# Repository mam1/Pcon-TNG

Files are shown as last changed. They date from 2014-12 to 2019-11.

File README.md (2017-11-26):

## PCON-TNG
------
### *** under construction and not stable ***
------
These are my notes on developing a multi channel programmable HVAC controller. The current iteration of the system is comprised of several ESP8266 modules, a BeagleBone Black (BBB), a BBB custom Control Cape and Digital IO Board(s) from Parallax. The system supports 16 channels.

A daemon (Dcon) is started as part of the boot process of the BeagleBone. The daemon decides if a channel should be on or off.  It does this by looking at a memory mapped file (ipc.dat). The memory mapped file creates a persistent space in virtual memory allowing processes to communicate.  It is maintained by a user interface process (Pcon).  Pcon is only active when a user is interacting with the system.  Temperature and humidity data is collected by ESP8266 modules. The ESP8266 modules read HDT22 sensors and use a wireless connection to post the data to the cloud (ThingSpeak) and to an Apache sever running on the BBB. A CGI on the BBB makes the data available to the daemon by updating shared memory and posts the data to a SQL database running on the Linux development machine.

A channel can be controlled by:

* time of day
* time of day and a sensor value
* manually

The BBB Control Cape (part of this project) maps 16 BeagleBone gpio pins to 2 2x10 pin headers.  Each header can drive 1 Parallax Digital IO board (DIOB).  It also connects 4 gpio pins to a heart beat display on the cape.

The Pcon application runs on the BBB.  It interacts with the daemon using shared memory.  Pcon provides a state machine driven user interface to configure channels, build and maintain schedules, query sensor and channel data, manually control channel states, etc.
- - - - - - - - -
#### Hardware
  * **BeagleBone Black Rev C - 4GB Flash, adafruit**
  * **BBB Control Cape**
    *  2 - 2 x 10 headers, DIOB control
            * Digital IO Board (DIOB), Sharp solid state relays part# S202S02F, Parallax
    *  4 - heart beat leds
  * **Wireless Sensors**
    * ESP8266 NodeMCU Dev Board, R2, Electro Dragon
    * DHT22 temperature/humidity sensor, Electro Dragon
    * 0.96” 128*64 OLED Display (i2c), Electro Dragon

##### BeagleBone GPIO assignments
                           {header,pin,gpio}
    * #define _CHAN0          {8,27,86}
    * #define _CHAN1          {8,28,88}
    * #define _CHAN2          {8,29,87}
    * #define _CHAN3          {8,30,89}
    * #define _CHAN4          {8,31,10}
    * #define _CHAN5          {8,32,11}
    * #define _CHAN6          {8,33,9}
    * #define _CHAN7          {8,34,81}
    * #define _CHAN8          {8,35,8}
    * #define _CHAN9          {8,36,80}
    * #define _CHAN10         {8,37,78}
    * #define _CHAN11         {8,38,79}
    * #define _CHAN12         {8,39,76}
    * #define _CHAN13         {8,40,77}
    * #define _CHAN14         {8,41,74}
    * #define _CHAN15         {8,42,75}
    * #define _HB0            {8,43,72}
    * #define _HB1            {8,44,73}
    * #define _HB2            {8,45,70}
    * #define _HB3            {8,46,71}

##### Parallel connection between BBB and DIOB(s)

#### Development Environment:

All code is stored on github.  The repository is cloned on two development machines.  At one site I have a Linux box running Mint 18.x and at the other I have have an iMac running OS X 10.10.x . The Bone is connected to my network. I can access it from either site using ssh. My makefiles use rsync to move the binaries from the development machines to the Bone as part of the build process. 

When cross compiling for the Bone on OS X I am using a tool chain I got from http://will-tm.com/cross-compiling-mac-os-x-mavericks. The only thing I needed to do was to create a case sensitive partition before copying the files from the .dmg file.  On the Linux box I tried installing a cross compile tool chain using the Mint software manager and experienced a lot of problems. After spending a lot of time dealing with missing files I gave up and installed the linaro-arm-linux-gnueabihf-4.9-2014.09_linux tool chain and it worked on the first try.

#### Language
* C - BBB
* Lua - ESP8266
* Bash Script
* Make

#### Envirnoment
* Development machines
	*	Mint 18.x - Intel Core i5-6600K 3.5GHz Quad-Core, Asus Z170-A ATX LGA1151 Motherboard Processor
	*	OS X 10.11.x - 3.4 GHz Intel Core i7 (iMac)
* BeagleBone Black (rev C)- Debian, jessie
* ESP8266 (nodeMCU dev board r2) - nodeMCU firmware 

#### Channels and Schedules 
A channel is controlled by a schedule. There is a different schedule for each day of the week. Each channel has it own set of schedules. Channels 0-7 can switch a 60 volt 1.1 amp loads.  Channels 8 -15 can switch 120 volt 8 amp loads.  Each channel can be set manually to on or off.  Channels and also be controlled by time of day, i.e. on at 8:00 off at 14:30 or sensor value and time.  When a channel is controlled by time and sensor once a minute the remote sensor value is compared to the value stored in the schedule for current time and day of the week. If the actual values exceeds the schedule value the channel is turned off when. If the schedule values is less than the actual value the channel is turned on.  

##### Schedules:
A schedule is a list of times and corresponding states.  A channel that is controlled by time will be a list of times and states.  For example, a schedule of:

* 1:00  on
* 13:00 off

will result in the channel turning on at 1:00AM and off at 1:00PM.  If the current time is between 13:00 and 24:00 or between 0:0 and 13:00 the channel will be off.  Between 1:00 and 13:00 it will be on. While a schedule of:

* 1:00  off
* 13:00 on 

will result in the channel being off between 1:00 - 13:00. It will be on at any time before 1:00 or after 13:00.

* 1:00  on
* 13:00 off
* 18:00 on

will result in the channel turning on at 1:00, off at 13:00 and on at 18:00.  If the current time is between 1:00 and 13:00 the channel will be on, between 13:00 and 18:00 it will be off, between 18:00 and 0:0 it will be on and between 0:0 and 13:00 it will also be on.  

#### Application Architecture
##### Interprocess Communication (BBB)
A memory mapped file is used to create a shared memory space in virtual memory.  This file contains communication, system, schedule and sensor data.  A daemon is started as part of the boot process on the BBB. If the daemon does not find the file it creates and initializes it.  Other processes can access this shared memory space.  Semaphores are used to control access to shared memory.
##### Processes
A deamon (Dcon) running on the BBB communicates with the DIOB(s).  It uses data located in a memory mapped file (ipc.dat) and the real time clock to determine the state of each channel. The state of each channel is reset once every minute. The daemon does not require any other processes to be active.

A command processor (Pcon) is the user interface to the system.  It allows the user to modify the data in shared memory.

ESP8266 modules run independently of other system components.  Each module posts its sensor readings to an Apache web server running on the BBB.  A CGI (Scon) loads the readings into  shared memory. 
##### Command Processor
The command processor is the most complex part of this project. 

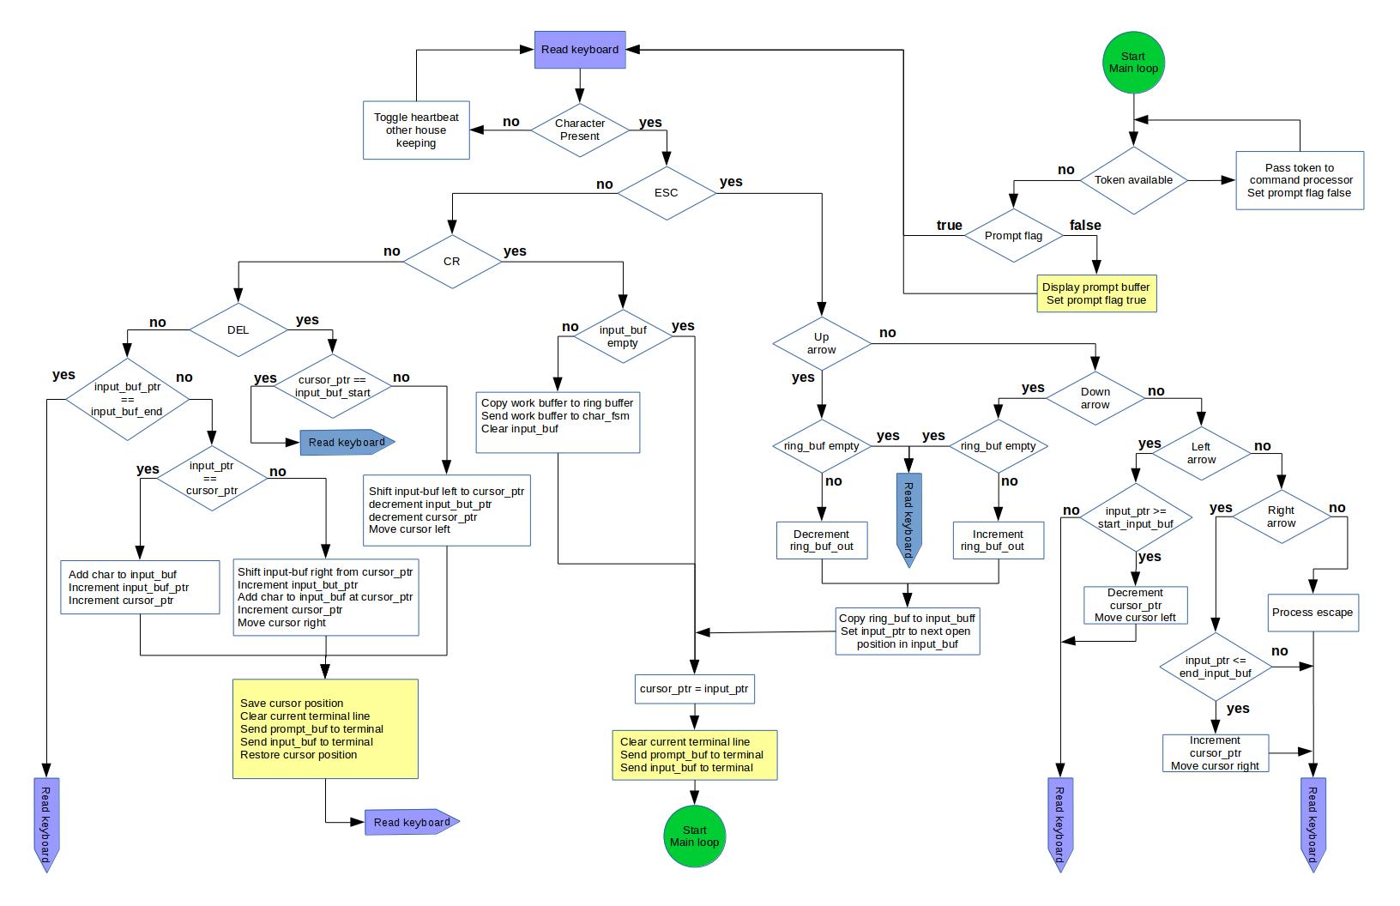
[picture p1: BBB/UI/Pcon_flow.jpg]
Pcon flow chart


The use of unbuffered input allows the application to mediately react to the press of the ECS key, but it requires that the command processor handle the arrow and delete keys. The command processor maintains a buffer which matches the user's screen. The process loops waiting for a character to be detected.  ESC, Del, up_arrow, down_arrow, left_arrow and right_arrow are handled directly.  An ESC will clear all buffers and reset both state machines.  The delete and arrow commands work as they do on the command line. Any other character is passed to the first state machine (char_fsm).  It parses the input stream into tokens and pushes them on to FIFO stack.  A CR will cause char_fsm to pass the stack of tokes to the command processor.  

The command processor pops tokens off the stack and feeds them to a second fsm (cmd_fsm).  It takes some action based on the token.  If more input is required it is popped off the stack, if present, or the user is prompted. This continues until the stack is empty. Then the command processor lets the cms_fsm know there is no more input then continues the main loop, waiting for user input. 

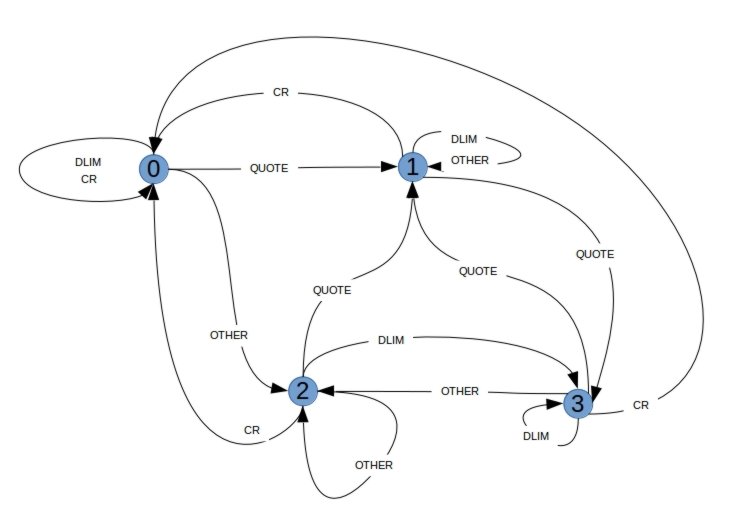
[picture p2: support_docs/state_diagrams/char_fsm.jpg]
character parser state diagram character parser FSM


When the main event loop detects a non-empty token stack it passes the stack to a second state machine (cmd_fsm) which processes the token stack. 

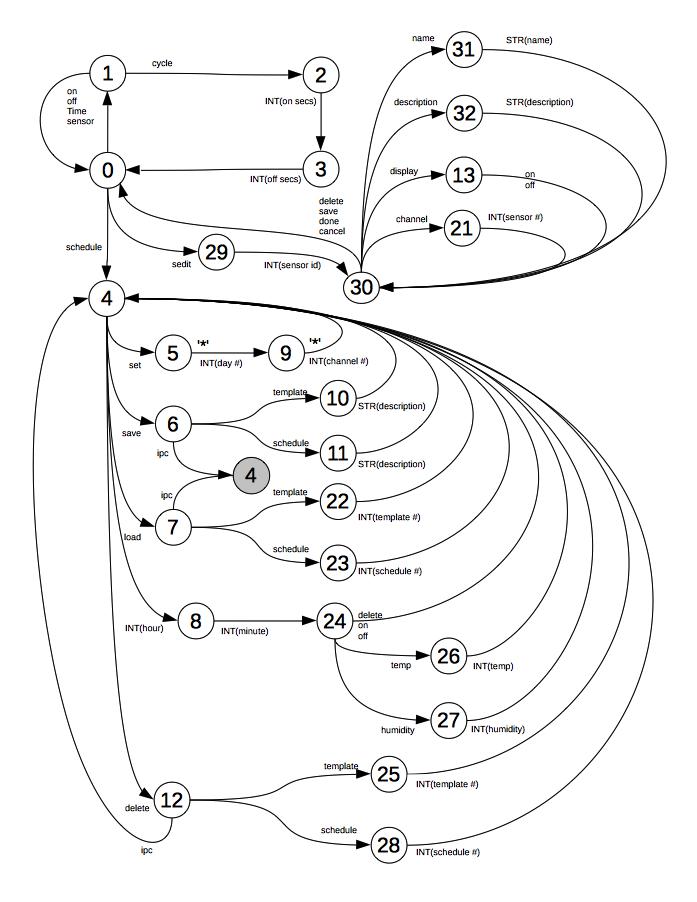
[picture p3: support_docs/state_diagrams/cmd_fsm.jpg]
command parser state diagram command parser FSM


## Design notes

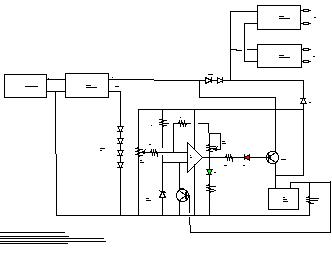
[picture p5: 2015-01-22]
support_docs/hardware_overview/power.jpeg

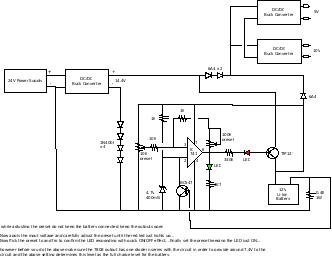
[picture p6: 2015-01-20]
support_docs/hardware_overview/power.jpg

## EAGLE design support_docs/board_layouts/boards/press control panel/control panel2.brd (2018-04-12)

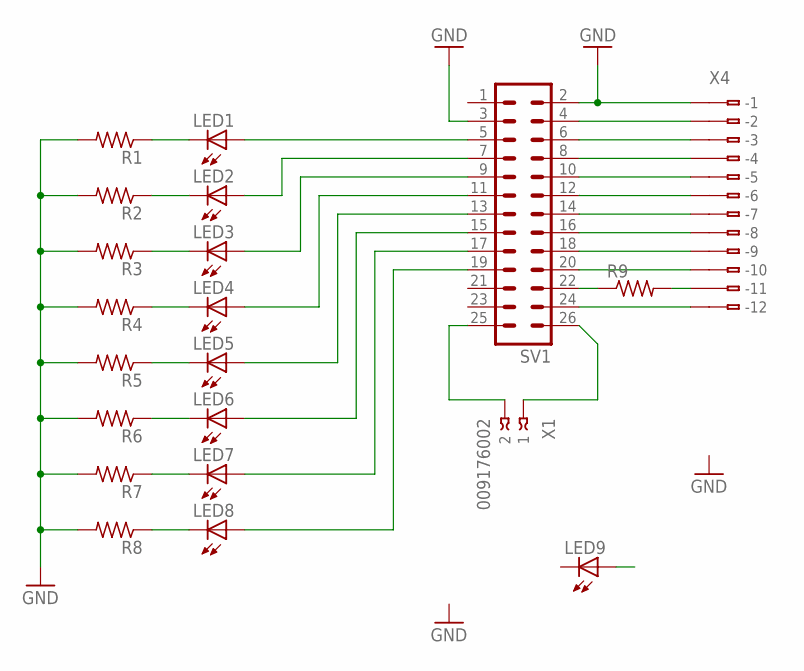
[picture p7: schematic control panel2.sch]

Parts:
LED1, LED2, LED3, LED4, LED5, LED6, LED7, LED8, LED9: LED3MM
R1, R2, R3, R4, R5, R6, R7, R8: R-US_0309/V; 0309V
R9: R-US_0204/7; 0204/7
SV1: MA13-2
X1: 009176002
X4: 233-212

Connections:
GND: R1.2, R2.2, R3.2, R4.2, R5.2, R6.2, R7.2, R8.2, SV1.2, SV1.3, X4.B1 (B-1)
unnamed: LED1.A, SV1.5
unnamed: LED2.A, SV1.7
unnamed: LED3.A, SV1.9
unnamed: LED4.A, SV1.11
unnamed: LED5.A, SV1.13
unnamed: LED6.A, SV1.15
unnamed: LED7.A, SV1.17
unnamed: LED8.A, SV1.19
unnamed: LED1.K (C), R1.1
unnamed: LED2.K (C), R2.1
unnamed: LED3.K (C), R3.1
unnamed: LED4.K (C), R4.1
unnamed: LED5.K (C), R5.1
unnamed: LED6.K (C), R6.1
unnamed: LED7.K (C), R7.1
unnamed: LED8.K (C), R8.1
unnamed: SV1.24, X4.B12 (B-12)
unnamed: SV1.4, X4.B2 (B-2)
unnamed: SV1.6, X4.B3 (B-3)
unnamed: SV1.8, X4.B4 (B-4)
unnamed: SV1.10, X4.B5 (B-5)
unnamed: SV1.12, X4.B6 (B-6)
unnamed: SV1.14, X4.B7 (B-7)
unnamed: SV1.16, X4.B8 (B-8)
unnamed: SV1.25, X1.2
unnamed: SV1.26, X1.1
unnamed: SV1.18, X4.B9 (B-9)
unnamed: SV1.20, X4.B10 (B-10)
unnamed: R9.1, SV1.22
unnamed: R9.2, X4.B11 (B-11)

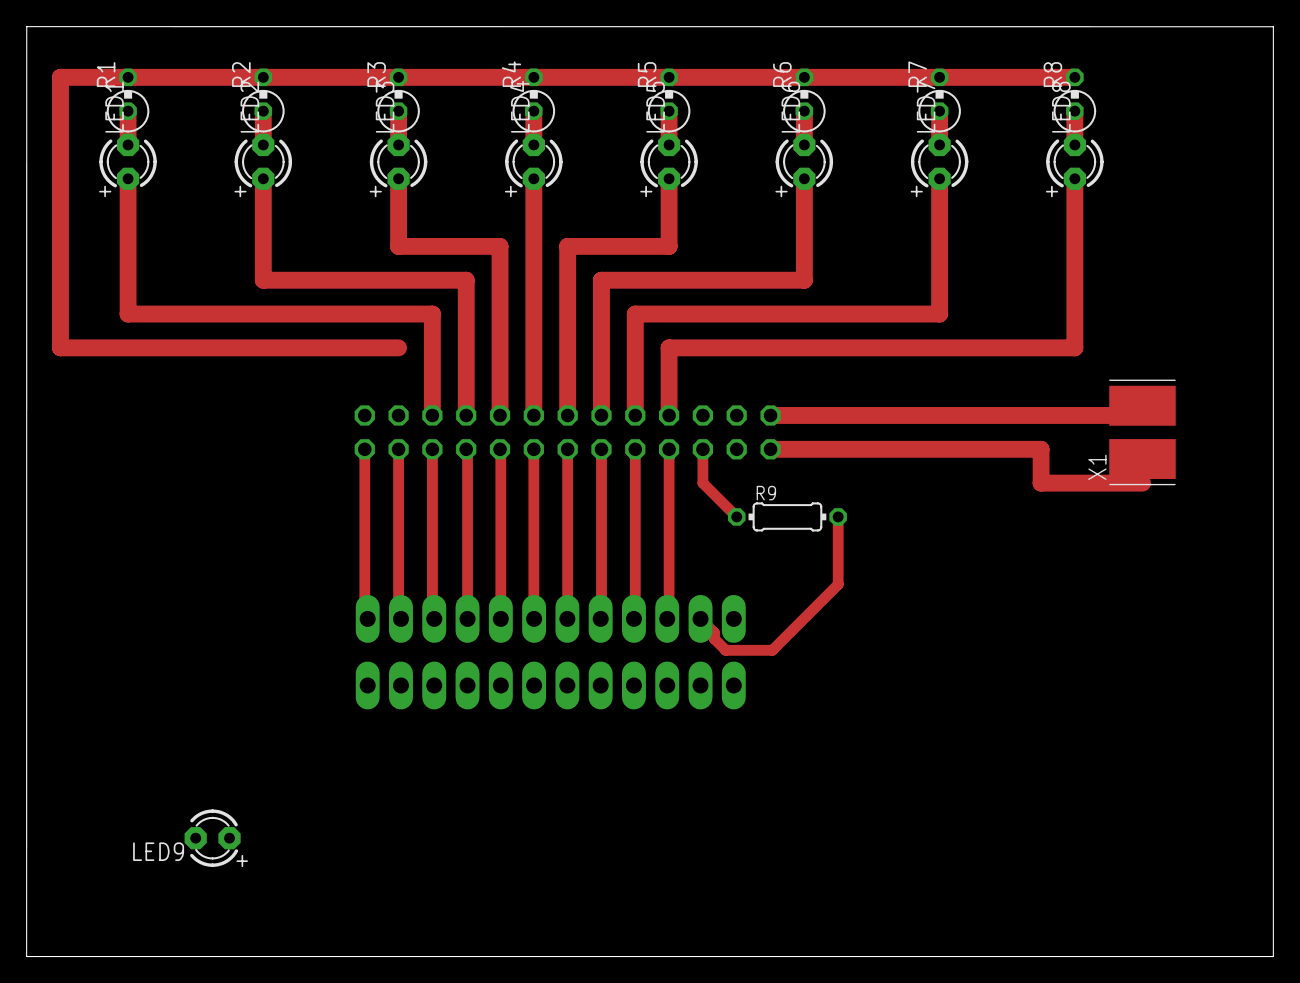
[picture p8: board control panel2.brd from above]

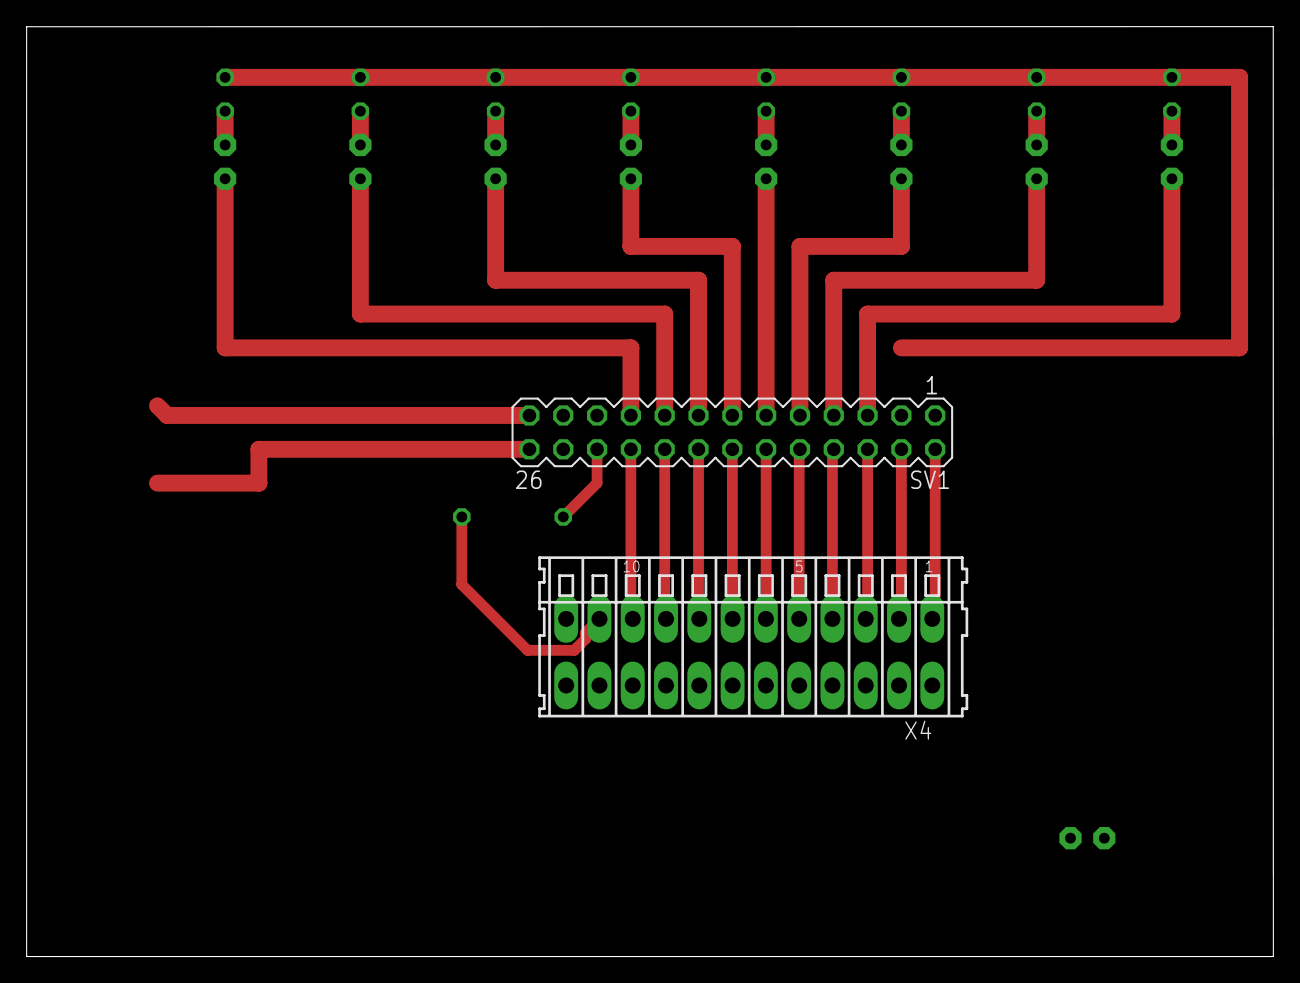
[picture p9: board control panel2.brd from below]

Board: 2 copper layers, 93.7 x 69.9 mm, 21 parts (2 on the bottom side), 31 nets.

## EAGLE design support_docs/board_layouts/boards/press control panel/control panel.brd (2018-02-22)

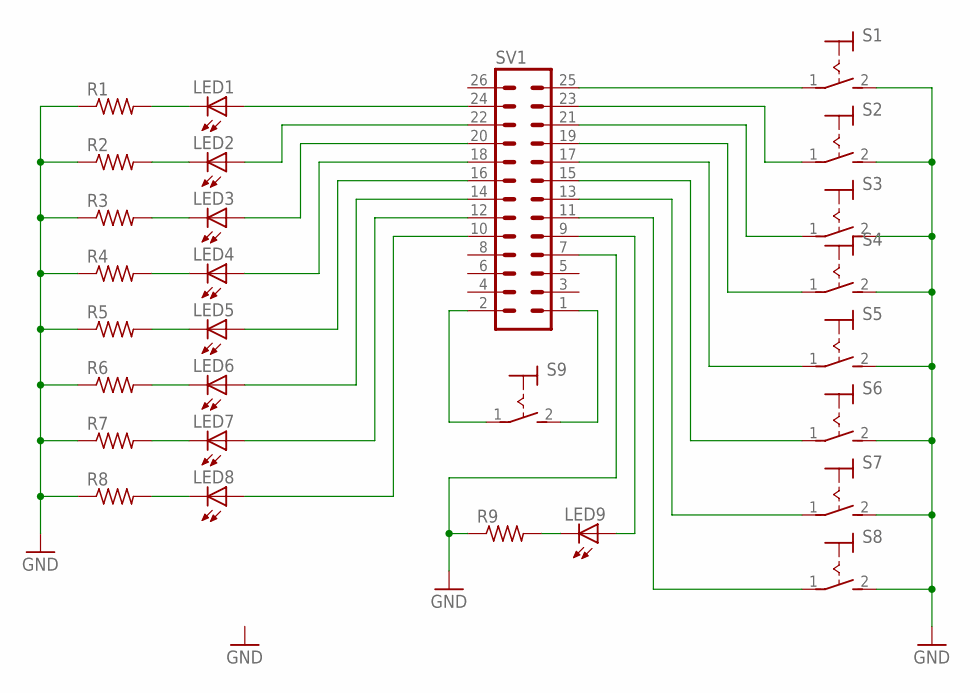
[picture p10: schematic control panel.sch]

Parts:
LED1, LED2, LED3, LED4, LED5, LED6, LED7, LED8, LED9: LED3MM
R1, R2, R3, R4, R5, R6, R7, R8, R9: R-US_0309/12; 0309/12
S1, S2, S3, S4, S5, S6, S7, S8, S9: MS243
SV1: MA13-2

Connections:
GND: R1.1, R2.1, R3.1, R4.1, R5.1, R6.1, R7.1, R8.1, R9.1, S1.2 (S), S2.2 (S), S3.2 (S), S4.2 (S), S5.2 (S), S6.2 (S), S7.2 (S), S8.2 (S), SV1.7, SV1.8
unnamed: LED1.A, SV1.24
unnamed: LED2.A, SV1.22
unnamed: LED3.A, SV1.20
unnamed: LED4.A, SV1.18
unnamed: LED5.A, SV1.16
unnamed: LED6.A, SV1.14
unnamed: LED7.A, SV1.12
unnamed: LED8.A, SV1.10
unnamed: LED1.K (C), R1.2
unnamed: LED2.K (C), R2.2
unnamed: LED3.K (C), R3.2
unnamed: LED4.K (C), R4.2
unnamed: LED5.K (C), R5.2
unnamed: LED6.K (C), R6.2
unnamed: LED7.K (C), R7.2
unnamed: LED8.K (C), R8.2
unnamed: S1.1, SV1.25
unnamed: S2.1, SV1.23
unnamed: S3.1, SV1.21
unnamed: S4.1, SV1.19
unnamed: S5.1, SV1.17
unnamed: S6.1, SV1.15
unnamed: S7.1, SV1.13
unnamed: S8.1, SV1.11
unnamed: S9.1, SV1.2
unnamed: S9.2 (S), SV1.1
unnamed: LED9.A, SV1.9
unnamed: LED9.K (C), R9.2

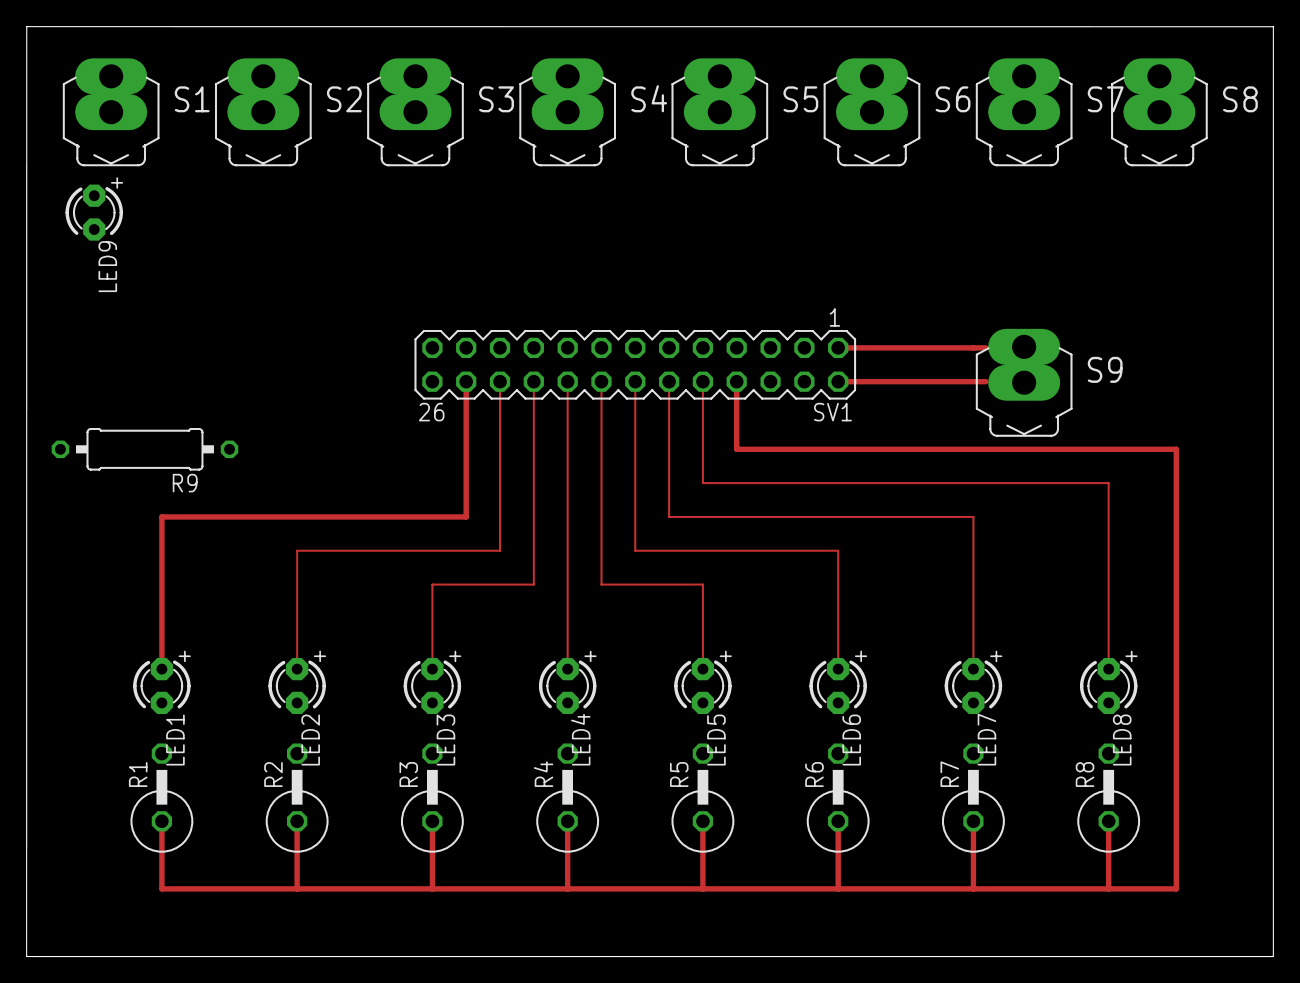
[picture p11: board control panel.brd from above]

Board: 2 copper layers, 93.7 x 69.9 mm, 28 parts (0 on the bottom side), 29 nets.

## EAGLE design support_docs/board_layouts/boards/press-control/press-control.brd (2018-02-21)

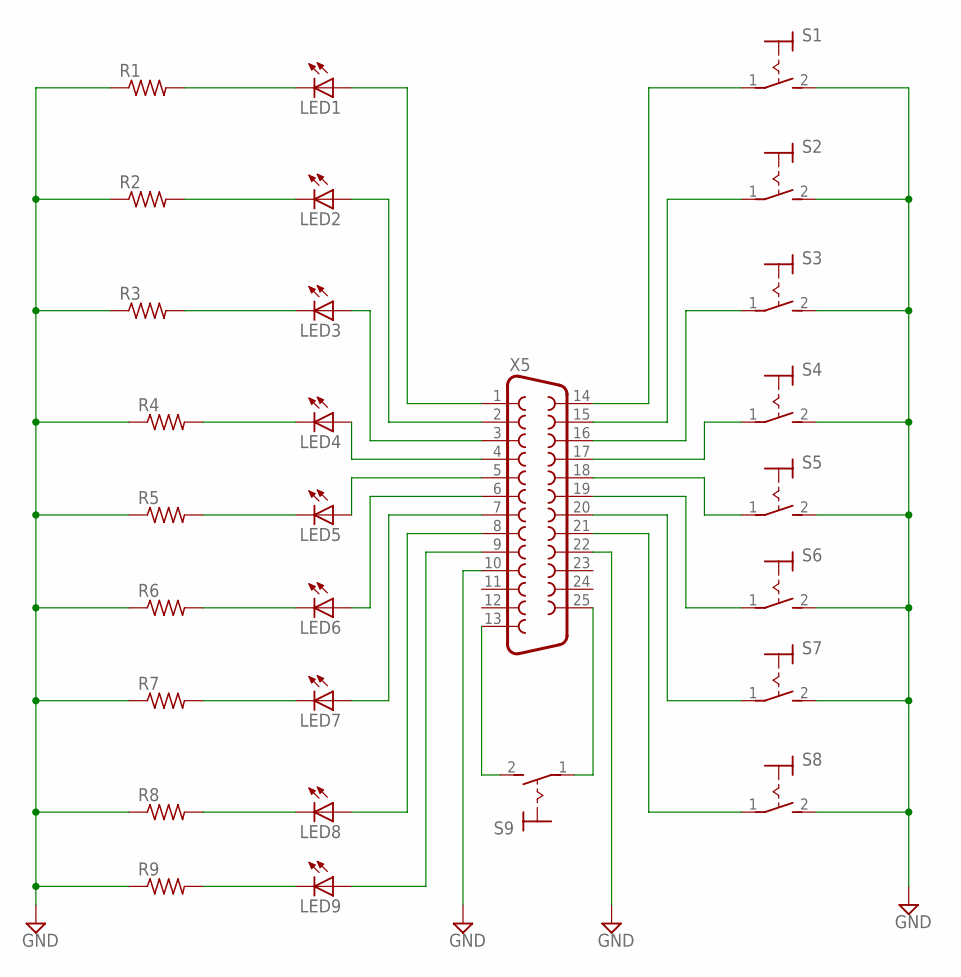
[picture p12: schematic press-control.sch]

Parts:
LED1, LED2, LED3, LED4, LED5, LED6, LED7, LED8, LED9: LED5MM
R1, R2, R3, R4, R5, R6, R7, R8, R9: R-US_0207/10; 0207/10
S1, S2, S3, S4, S5, S6, S7, S8, S9: MS243
X5: DB25_FEMALEV; F25V

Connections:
GND: R1.1, R2.1, R3.1, R4.1, R5.1, R6.1, R7.1, R8.1, R9.1, S1.2 (S), S2.2 (S), S3.2 (S), S4.2 (S), S5.2 (S), S6.2 (S), S7.2 (S), S8.2 (S), X5.10, X5.22
unnamed: LED1.K (C), R1.2
unnamed: LED2.K (C), R2.2
unnamed: LED3.K (C), R3.2
unnamed: LED4.K (C), R4.2
unnamed: LED5.K (C), R5.2
unnamed: LED6.K (C), R6.2
unnamed: LED7.K (C), R7.2
unnamed: LED8.K (C), R8.2
unnamed: LED4.A, X5.4
unnamed: LED5.A, X5.5
unnamed: LED3.A, X5.3
unnamed: LED2.A, X5.2
unnamed: LED1.A, X5.1
unnamed: LED6.A, X5.6
unnamed: LED7.A, X5.7
unnamed: LED8.A, X5.8
unnamed: S5.1, X5.18
unnamed: S4.1, X5.17
unnamed: S3.1, X5.16
unnamed: S2.1, X5.15
unnamed: S1.1, X5.14
unnamed: S6.1, X5.19
unnamed: S7.1, X5.20
unnamed: S8.1, X5.21
unnamed: S9.2 (S), X5.13
unnamed: S9.1, X5.25
unnamed: LED9.A, X5.9
unnamed: LED9.K (C), R9.2

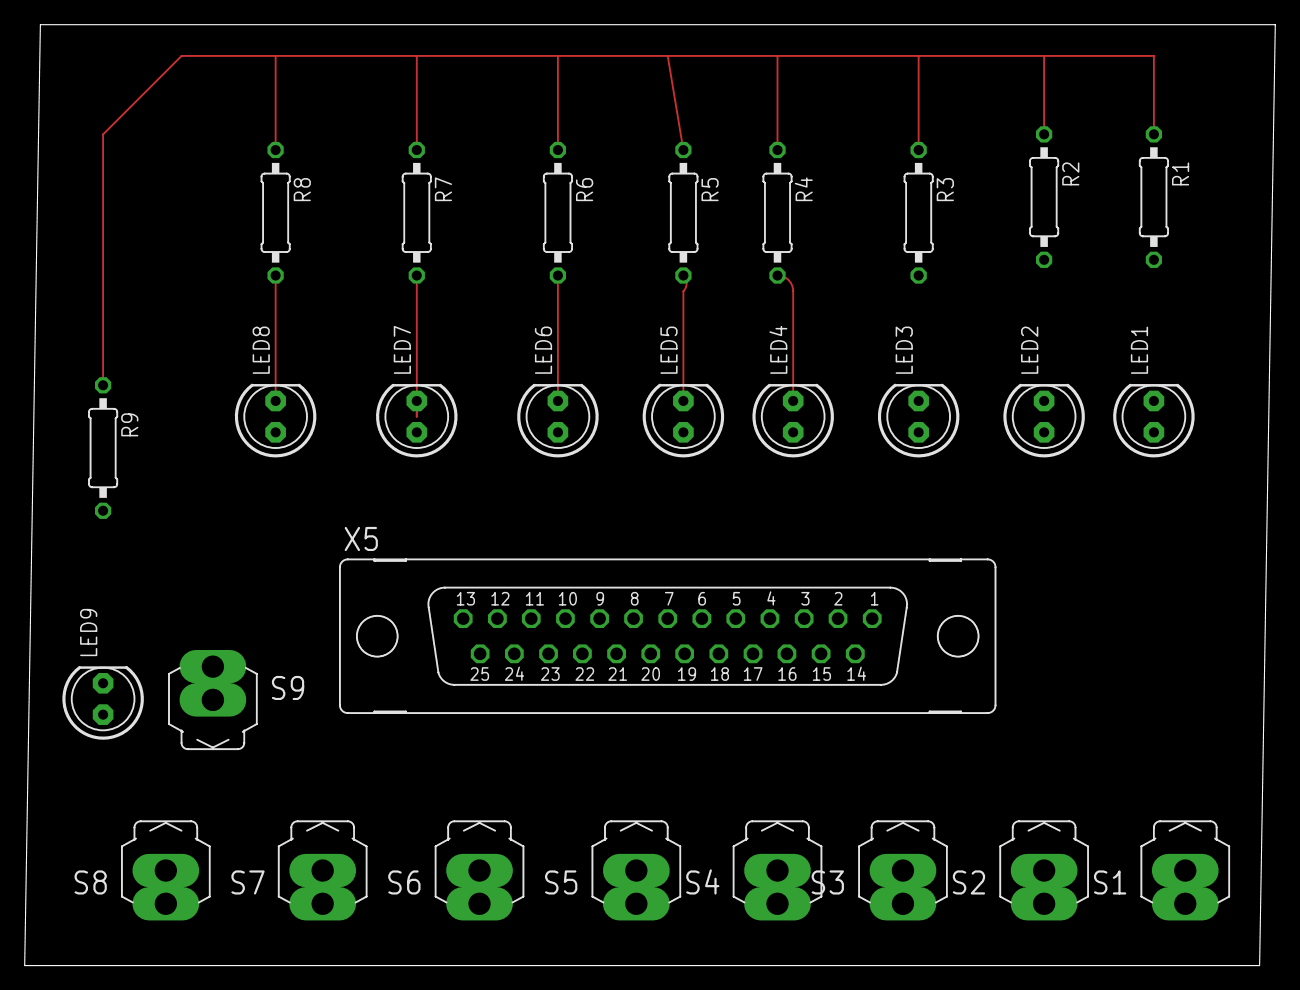
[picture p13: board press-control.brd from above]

Board: 2 copper layers, 101.3 x 76.2 mm, 28 parts (0 on the bottom side), 29 nets.

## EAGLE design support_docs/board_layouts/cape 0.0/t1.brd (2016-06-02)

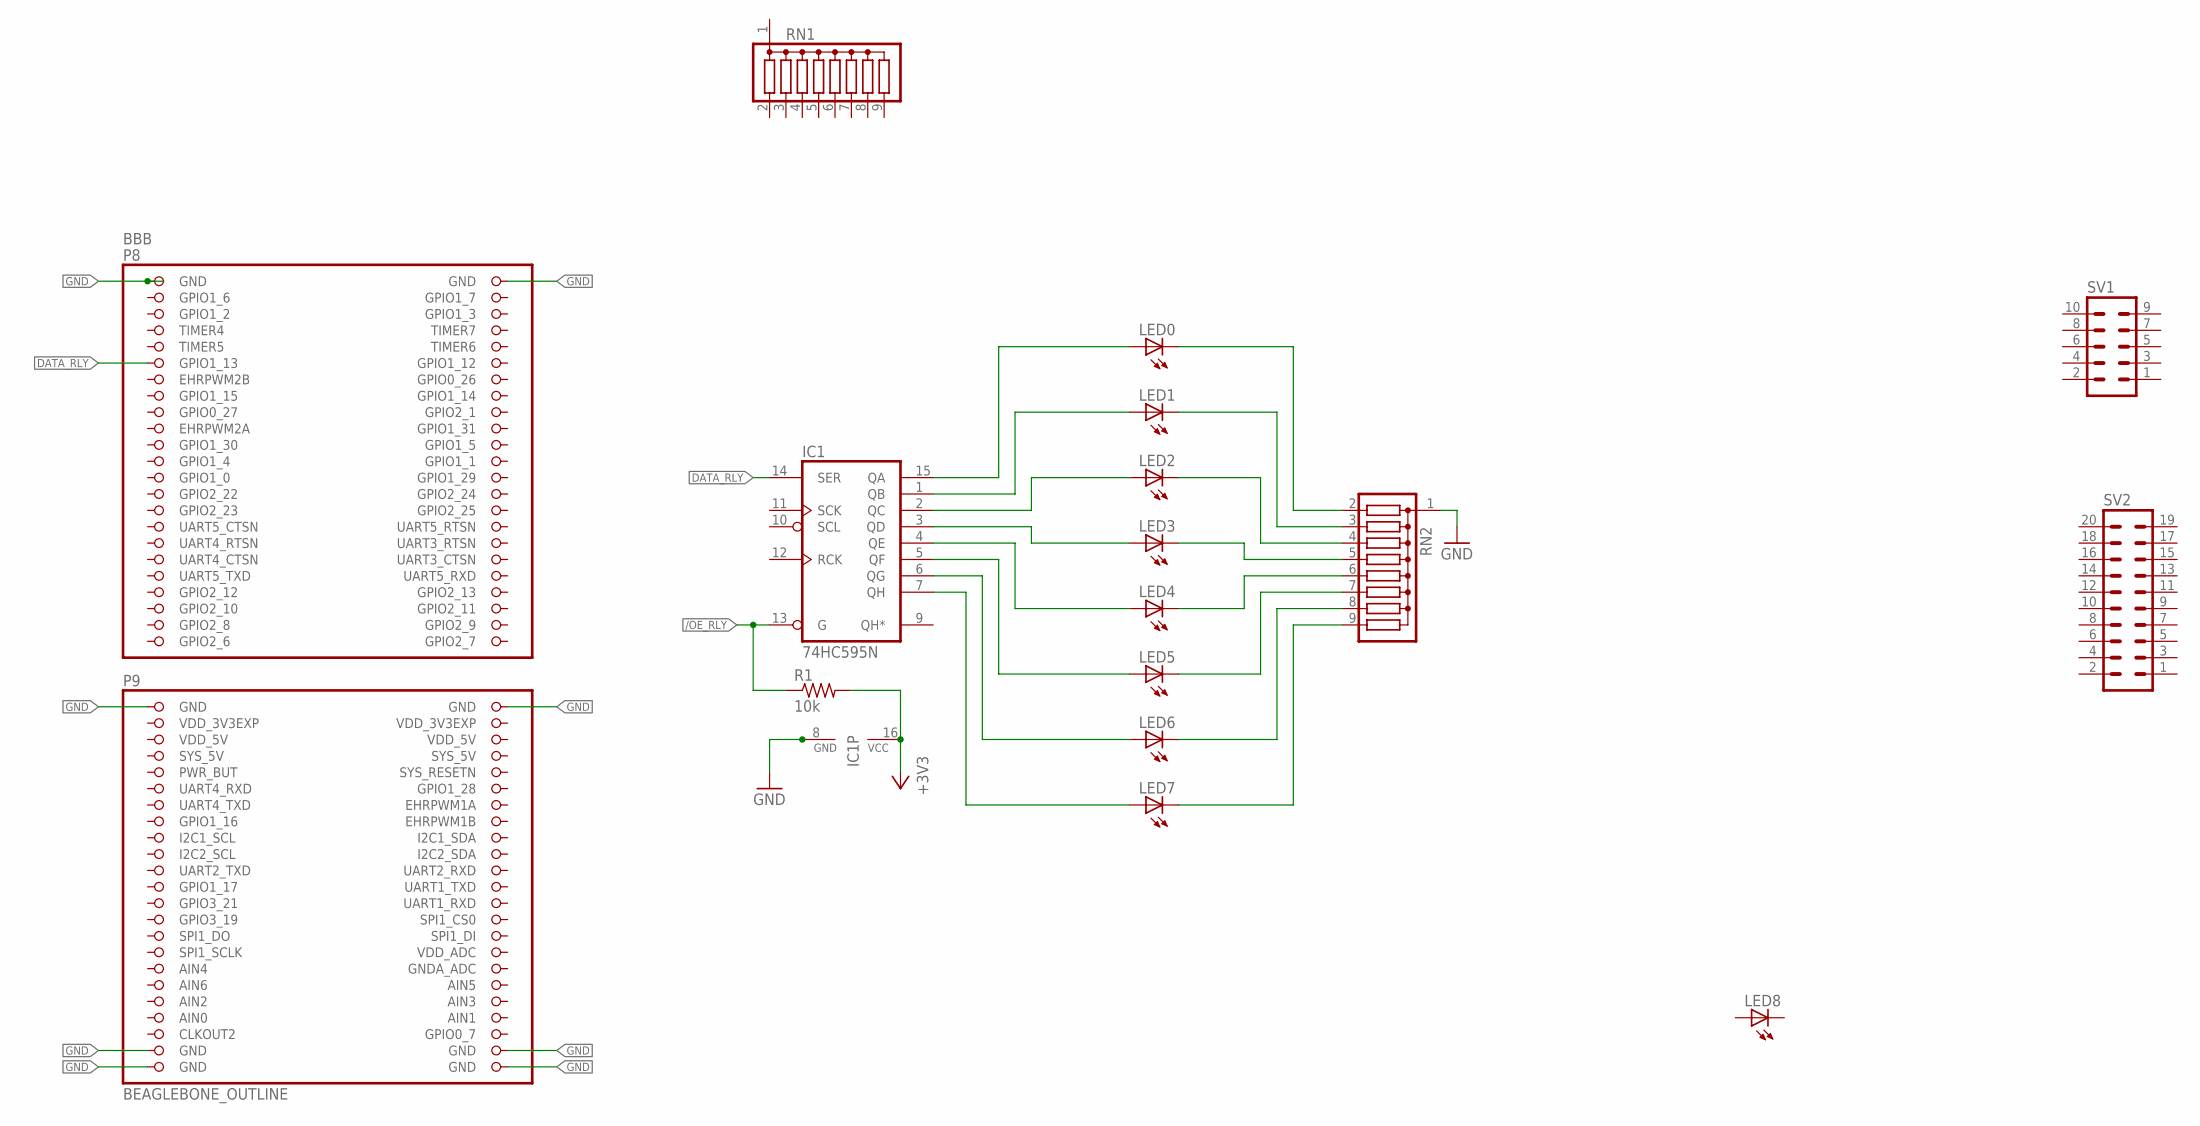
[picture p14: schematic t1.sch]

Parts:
BBB: BEAGLEBONE_OUTLINE; BEAGLEBONE_SHIELD
IC1: 74HC595N; DIL16
LED0, LED1, LED2, LED3, LED4, LED5, LED6, LED7, LED8: LED3MM
R1: 10k; 0207/12
RN1, RN2: G08R; SIL9
SV1: MA05-2
SV2: MA10-2

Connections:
+3V3: IC1.16 (VCC), R1.2
/OE_RLY: IC1.13 (G), R1.1
AIN0: BBB.85 (AIN0)
DATA_RLY: BBB.11 (GPIO1_13), IC1.14 (SER)
GND: BBB.1 (GND), BBB.2 (GND), BBB.47 (GND), BBB.48 (GND), BBB.89 (GND), BBB.90 (GND), BBB.91 (GND), BBB.92 (GND), IC1.8 (GND), RN2.1
unnamed: LED7.K (C), RN2.9
unnamed: LED1.K (C), RN2.3
unnamed: LED3.K (C), RN2.5
unnamed: LED2.K (C), RN2.4
unnamed: LED4.K (C), RN2.6
unnamed: LED6.K (C), RN2.8
unnamed: LED0.K (C), RN2.2
unnamed: IC1.15 (QA), LED0.A
unnamed: IC1.1 (QB), LED1.A
unnamed: LED5.K (C), RN2.7
unnamed: IC1.2 (QC), LED2.A
unnamed: IC1.3 (QD), LED3.A
unnamed: IC1.4 (QE), LED4.A
unnamed: IC1.5 (QF), LED5.A
unnamed: IC1.6 (QG), LED6.A
unnamed: IC1.7 (QH), LED7.A
SYS_5V: BBB.53 (SYS_5V)
VDD_3V3EXP: BBB.49 (VDD_3V3EXP), BBB.50 (VDD_3V3EXP)
VDD_5V: BBB.51 (VDD_5V), BBB.52 (VDD_5V)

Board: 2 copper layers, 16 parts (0 on the bottom side), 22 nets, no tracks yet.

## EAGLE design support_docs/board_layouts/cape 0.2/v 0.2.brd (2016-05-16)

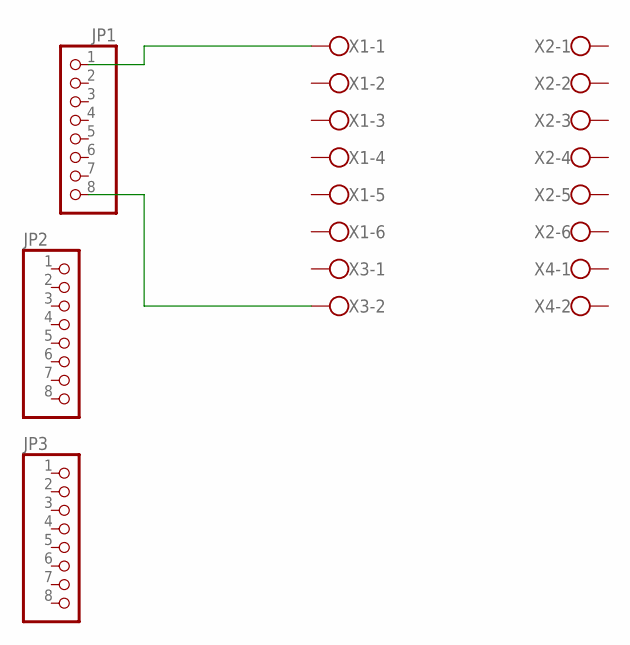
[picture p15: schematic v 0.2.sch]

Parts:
JP1, JP2, JP3: PINHD-1X8; 1X08
X1, X2, X3, X4: W237-136

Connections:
unnamed: JP1.1, X1.1
unnamed: JP1.8, X3.2

Board: 2 copper layers, 7 parts (0 on the bottom side), 2 nets, no tracks yet.

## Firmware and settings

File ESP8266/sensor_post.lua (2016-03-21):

------------------------------------------------
-- read sensor and post data to ThingSpeak 
-- and to my local Apache2 server
------------------------------------------------

version = "0.9.6"
CHANNEL_API_KEY = "WLDS1EKH6GRTK2QN"
delay = 60000
PINS =   {7,7}  --DHT22 data pin
FIELDS = {1,2}  --ThingSpeak fields
pinptr = 1

tempStr = " "
hmdyStr = " "

-- setup I2c and connect display
function init_i2c_display()
     -- SDA and SCL can be assigned freely to available GPIOs
     local sda = 6 -- GPIO14
     local scl = 5 -- GPIO12
     local sla = 0x3c
     print("  initializng I2c OLED display on pins "..sda.." and "..scl)    
     i2c.setup(0, sda, scl, i2c.SLOW)
     disp = u8g.ssd1306_128x64_i2c(sla)
     disp:setFont(u8g.font_6x10)
     disp:setFontRefHeightExtendedText()
     disp:setDefaultForegroundColor()
     disp:setFontPosTop()
     disp:setColorIndex(1)
end

-- update OLED display
function dispPage(line,text1,text2,text3)
   --picture loop
  disp:firstPage() 
  while disp:nextPage() do 
    disp:drawStr(0,line,text1)
    disp:drawStr(0,(line+15),text2)
    disp:drawStr(0,(line+27),text3)
    disp:drawStr(0,(line+45),"v "..version)
  end
end

--get data from DHT22 sensor on <pin>
function rdDHT22(pin)
	local tmp, hmd
    print("\n  reading pin "..PINS[pinptr])
    dht22 = require("dht22_min")
	--read sensor
    dht22.read(PINS[pinptr])
    tmp = dht22.getTemperature()
    hmd = dht22.getHumidity()
	if tmp == nil then
    	print("*** Error reading temperature from DHT22")
    end
    if hmd == nil then
        print("*** Error reading humidity from DHT22")
    end
	--release DHT22 module
    dht22 = nil
    package.loaded["dht22"]=nil
	return tmp, hmd 
end

--post data <value> to ThingSpeak api key <key>, field <field>
function post(key,field,value)
    print("    posting pin "..PINS[pinptr].." data to field "..field.." value is "..value)   
    connout = nil
    connout = net.createConnection(net.TCP, 0)
    connout:on("receive", function(connout, payloadout)
        if (string.find(payloadout, "Status: 200 OK") ~= nil) then
            print("    Posted OK");
        end
    end)
    connout:on("connection", function(connout, payloadout) 
        print ("    Posting...");       
        connout:send("GET /update?api_key="
        .. key
        .. "&field"
        .. field
        .."=" 
        .. value
        .. " HTTP/1.1\r\n"
        .. "Host: api.thingspeak.com\r\n"
        .. "Connection: close\r\n"
        .. "Accept: */*\r\n"
        .. "User-Agent: Mozilla/4.0 (compatible; esp8266 Lua; Windows NT 5.1)\r\n"
        .. "\r\n")
    end)
    connout:on("disconnection", function(connout, payloadout)
        connout:close();
        collectgarbage(); 
    end)
    connout:connect(80,'api.thingspeak.com')
end 

--post data <value> to local apache2 server api key <key>, field <field>
function posta(key,field,value)
    print("    posting pin "..PINS[pinptr].." data to field "..field.." value is "..value)   
    connout = nil
    connout = net.createConnection(net.TCP, 0)
    connout:on("receive", function(connout, payloadout)
        if (string.find(payloadout, "Status: 200 OK") ~= nil) then
            print("    Posted OK");
        end
    end)
    connout:on("connection", function(connout, payloadout) 
        print ("    Posting...");       
        connout:send("GET /cgi-bin/Scon"
        .. "&field"
        .. field
        .."=" 
        .. value
        .. " HTTP/1.1\r\n"
        .. "Host: 192.168.254.34:8080\r\n"
        .. "Connection: close\r\n"
        .. "Accept: */*\r\n"
        .. "User-Agent: Mozilla/4.0 (compatible; esp8266 Lua; Windows NT 5.1)\r\n"
        .. "\r\n")
    end)
    connout:on("disconnection", function(connout, payloadout)
        connout:close();
        collectgarbage(); 
    end)
    connout:connect(80,'192.168.254.34:8080')
end


-- update temperature and humidity
function update()
	local t, h,send
    t, h = rdDHT22(PINS[pinptr]) --read the HDT22 sensor
    print("***")
    if pinptr % 2 ~= 0 then
        send = (t*9)/5 + 320
    	print("    posting temperature ")
        tempStr = "    "..tostring(send/10).."."..tostring(send % 10).." deg F"  
    else
        send = h
        print("    posting humidity ")
        hmdyStr = "    "..tostring(send/10).."."..tostring(send % 10).." %" 
    end	
    dispPage(10,"Office Sensor",tempStr,hmdyStr)
    post(CHANNEL_API_KEY,FIELDS[pinptr],tostring(send/10).."."..tostring(send % 10))
	pinptr = pinptr + 1
	if pinptr > #PINS then pinptr = 1 end
end

-- ************** start main function ********************

    print("\n\n*** sensor_post.lua  version "..version.." ***")
    if (#PINS ~= #FIELDS) then 
        print("\n***** pin count and field count do not match\naborting")
    else
        print("  reading "..(#PINS / 2).." HDT22 sensor\n  posting data to ThingSpeak api key "..CHANNEL_API_KEY)
        init_i2c_display()  -- initialise the OLED display 
        dispPage(10," thermo.lua - "," "," ")
        print("  running update every "..delay.."ms\n  starting timer")
        tmr.alarm(4, delay, 1, update) -- execute update function every <delay> micro seconds
    end

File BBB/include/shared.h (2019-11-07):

#ifndef _SHARE_H_
#define _SHARE_H_

/* version info */
#define _TAG		"v1.6"

/* file names */
#define _FILE_NAME_SIZE 		50
// #define _CGI_DATA_FILE_PREFIX	"/media/TOSHIBA/sensor"		// cgi generated log of sensor data
// #define _CGI_DATA_FILE_SUFIX	".dat"							// cgi generated log of sensor data
#define _SENSOR_DATA_FILE_NAME		"/media/data/sensors/sensor.dat" 		// USB drive collecting sensor readingss
#define _CGI_LOG_FILE_NAME			"/media/data/logs/CGI.log"				// log file name
// #define _SYSTEM_FILE_NAME			"/home/Pcon-data/sys.dat"			// system data file
#define _IPC_FILE_NAME				"/home/Pcon-data/ipc.dat"   			// memory mapped ipc file
#define _IPC_FILE_BACKUP_NAME		"/home/Pcon-data/ipc.bkup"   			// ipc backup file 
#define _TRACE_FILE_NAME			"/hmedia/data/trace/Pcon-trace.dat" 	// trace file
#define _DAEMON_LOG 				"/home/mam1/logs/daemon.log" 			    // daemon log file name
#define _SENSOR_MASTER_FILE_NAME    "/media/Raid/sensor logs/master.dat"	// cumulative history of sensor readings
#define _PID_FILE_NAME 				"/run/Dcon.pid"							// daemon pid

/* semaphore key */
#define _SEM_KEY 				1234321

/* character parser fsm */
#define _CHAR_TOKENS     		5
#define _CHAR_STATES     		4
#define _MAX_TOKEN_SIZE			128
#define _TT_INT					-1
#define _TT_STR					-2
#define _TT_NULL				-3
#define _TT_UNREC				-4

/* command parser fsm */
#define _CMD_TOKENS     		41
#define _CMD_STATES     		35 

/* key codes */
#define _ESC        27
#define _SPACE      32
#define _COLON      58
#define _SLASH      47
#define _COMMA      44
#define _BS         8
#define _DEL		127
#define _QUOTE      34
#define _CR         13
#define _NL 		10
#define _FF 		12
#define _EOF		0
#define _NO_CHAR    255
#define _DELIMITER	28	
#define _UPA		124

/* buffers */
#define _INPUT_BUFFER_SIZE		60
#define _TOKEN_BUFFER_SIZE		_INPUT_BUFFER_SIZE
#define _PROMPT_BUFFER_SIZE		500
#define _CMD_BUFFER_DEPTH 		10 
#define _TRACE_BUFFER_SIZE 		128		
#define _SCREEN_BUFFER_SIZE		_INPUT_BUFFER_SIZE + _PROMPT_BUFFER_SIZE

/* sensor parameteres */
#define _NUMBER_OF_SENSORS		20
#define _GROUP_NAME_SIZE 		9
#define _DESCRIPTION_NAME_SIZE	_MAX_TOKEN_SIZE
#define _MAX_SENSOR_ID			99

/* channel parameters */
#define _NUMBER_OF_CHANNELS 	16
#define _CHANNEL_NAME_SIZE		20

/* schedule parameters */
#define _SCHEDULE_NAME_SIZE		40
#define _MAX_SCHEDULE_RECS		50
#define _MAX_SCHEDULES			24
#define _ALL_CHANNELS			99
#define _ALL_DAYS				99

/* template library parameters */
#define _MAX_TEMPLATES			10
#define _TEMPLATE_NAME_SIZE		40

// #define _SCHEDULE_SIZE			_MAX_SCHEDULE_RECS + 1
// #define _SCHEDULE_BUFFER		128

#define	_BYTES_PER_INT 			4
#define _BYTES_PER_SCHEDULE 	_SCHEDULE_SIZE * _BYTES_PER_INT
#define _BYTES_PER_DAY 			_NUMBER_OF_CHANNELS * _BYTES_PER_SCHEDULE 	

/*	gpio pin assignment {header,pin,gpio}  	*/
// #define _CHAN0			{8,17,27}
// #define _CHAN1			{8,16,46}
// #define _CHAN2			{8,26,61}
// #define _CHAN3			{8,18,65}
// #define _CHAN4			{9,15,48}
// #define _CHAN5			{9,12,60}
// #define _CHAN6			{9,41,20} 
// #define _CHAN7			{9,23,49}
// #define _CHAN8			{9,18,4} //
// #define _CHAN9			{8,36,80}
// #define _CHAN10			{8,37,78}
// #define _CHAN11			{8,38,79}
// #define _CHAN12			{8,39,76}
// #define _CHAN13			{8,40,77} 
// #define _CHAN14			{8,41,74} 
// #define _CHAN15			{8,42,75}
// #define _HB0 			{8,7,66}
// #define _HB1 			{8,9,67}
// #define _HB2 			{8,8,69}
// #define _HB3 			{8,10,68}


#define _CHAN0			{8,27,86}
#define _CHAN1			{8,28,88}
#define _CHAN2			{8,29,87}
#define _CHAN3			{8,30,89}
#define _CHAN4			{8,31,10}
#define _CHAN5			{8,32,11}
#define _CHAN6			{8,33,9}
#define _CHAN7			{8,34,81}
#define _CHAN8			{8,35,8}
#define _CHAN9			{8,36,80}
#define _CHAN10			{8,37,78}
#define _CHAN11			{8,38,79}
#define _CHAN12			{8,39,86}
#define _CHAN13			{8,40,77}
#define _CHAN14			{8,41,74}
#define _CHAN15			{8,42,75}
#define _HB0 			{8,7,66}
#define _HB1 			{8,9,67}
#define _HB2 			{8,8,69}
#define _HB3 			{8,10,68}


/* general */
#define _DAYS_PER_WEEK 	7
#define _ON 			1
#define _OFF 			0
#define _TRUE 			1
#define _FALSE			0

/* macros */
#define handle_error(msg) \
   do { perror(msg); exit(EXIT_FAILURE); } while (0)

#endif	//_SHARE_H_

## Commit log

2014-12-15 trying to get the prop make files working
2014-12-16 working on prop make file
2014-12-20 prop make working under os x
2014-12-21 prop makefile finally working, but no communication with the bone
2014-12-30 working on prop code
2015-01-03 working on board lyouts
    [C3-db-v1.fzz, C3_daughter_board.fzz, MID400.fzz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]
2015-01-16 make is still not working from messing with tool chains
2015-01-18 bone tool chain on Mint not working
2015-01-29 messing with propeller make file
2015-02-11 template maint seems to be working, but it does not handle input error well
    [shared.h]
2015-02-11 templete index is screwed up
2015-02-22 mege fixed template edit code back into dev branch
    [shared.h]
2015-02-27 first cut send schedule working
2015-03-25 adding new bone to prop io routines
2015-05-18 packet processing code working, schedule frame processing working
2015-05-20 cleaned up directory
    [C3-db-v1.fzz, C3_daughter_board.fzz, MID400.fzz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]
2015-05-30 bone / prop communication not working
2015-05-31 working on Tbone, UART initialization working
2015-05-31 monitorint UART1 with logic analizer, bone is sending correctly
    [shared.h]
2015-06-01 prop echo working, sending chars from bone to prop working
2015-06-02 ack from the prop to the bone working
2015-06-05 replaced serial iocode with packet code
    [shared.h]
2015-06-10 schedule transfer from C3 to bone is kind of working, but fails after loadind ~40 schedules with a read timeout
    [shared.h]
2016-01-13 fixed problem with setting a channel to time control
    [shared.h]
2016-01-19 adding ipc code, not working
    [shared.h]
2016-01-29 back from merge woring on make anagin
    [C3-db-v1.fzz, C3_daughter_board.fzz, MID400.fzz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]
2016-01-31 adding led contron to daemon
2016-02-02 led seequence working in the daemon
2016-02-03 fix ? in Pcon
    [shared.h]
2016-02-05 fixed problems with PCF8563 code
    [PCF8563.c]
2016-02-15 messing with gpio iolib crashing
    [shared.h]
2016-02-16 added led + 470 ohm resisters to breadboard, problem with r5 led
    [shared.h]
2016-03-06 working, driving leds on bread board
2016-03-08 test-cgi first cut working
2016-03-10 my cape layout added - frirzing
    [my cape.fzz]
2016-03-10 adding relay code
2016-03-11 not lighting leds
2016-03-11 something is screwed up with the gpio to header mapping
2016-03-14 controll working out leds, but wrong led number
2016-03-14 working on cap layout
    [cc1.brd, cc1.sch, my cape.fzz]
2016-03-14 channels 0-7 driving leds corrctly
2016-03-14 shift register wired correctly, all leds working as expected
    [shared.h]
2016-03-21 time control of realys not working
    [PCF8563.c]
2016-03-22 ESP8266 sending GET to apache2 on the bone correctly
    [s1.lua]
2016-03-22 add code to read DHT22 sensor, working
2016-03-23 create file name based on sensor number
2016-03-23 time controled schedules working correctly
    [shared.h]
2016-03-23 started to add sensor eval code, but going to try to lose the bit fiddeling
2016-03-25 adding code to allow sensor id to be added to cahnnel data
2016-03-25 sensor id maint working
2016-03-28 switched test-schedule to use new libbrary functions
2016-04-19 version 9.0.0 schedules controlling leds, needs more testing
2016-04-24 adding board schmatics
2016-04-25 temp controled channels implemented but not woring correctly
    [shared.h]
2016-04-27 build a seperate test program for pid code
2016-04-27 test pid working
2016-04-29 cape layout
    [t1.sch]
2016-04-29 working on board layout
    [t1.sch]
2016-05-02 add list maint code
    [t1.brd, t1.sch]
2016-05-05 testing and updating cape layout
    [t1.brd, t1.sch]
2016-05-16 working on cape layout
    [t1.brd, t1.sch, v 0.1.brd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]
2016-05-17 add socket test before branching
    [c3.sch]
2016-05-21 messing with socket code
2016-05-22 still not working corremtly, record count is getting trashed
    [shared.h]
2016-06-02 add tool chain info
2016-06-05 changed trace preprocessor functions
2016-06-05 up version improved trace start more testing
2016-06-11 messing with eagle directories
    [C3-db-v1.fzz, C3_daughter_board.fzz, MID400.fzz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]
2016-06-17 ajust led cycle timing for daemon
2017-01-22 added second try on open sensor log
2017-01-25 grab command is not working
    [shared.h]
2017-01-29 addd code to process sensor log data
2017-01-31 new sensor log processing code running on Mint box
2017-02-02 fixed problem with ESP8266 aquiring IP
    [init.lua, startup.lua]
2017-02-05 handeling floaing point temp and humidity correctly
    [startup.lua]
2017-02-05 convering sensor data log to float
2017-02-06 sensor data log converted to float
2017-02-07 fixed sensor display in cmd_fsm
    [shared.h]
2017-02-07 multipal sensors working
2017-02-08 ready to add new states to handle sensor list maint
2017-02-08 add new sensor
2017-02-08 update for sensor maint
2017-02-09 adding code to maitian sensor list
2017-02-10 chasing problem with input buffer overflow
    [shared.h]
2017-03-17 switching system clock for rtc
2017-04-01 changes to support second bone
    [concape.sch]
2017-04-02 adding new cap design
    [onCape.sch]
2017-04-16 fixed most complier warings
    [PCF8563.c, shared.h]
2017-04-16 remove debug printf(s)
2017-04-17 sensor maint working, needs cleanup
2017-04-24 formating sensor list output, looking good
2017-05-02 working on sensor data display
2017-05-07 switch beaglebone images
2017-05-08 switched to new io lib
2017-05-14 controling pind by calling shell command <config-pin>
2017-05-15 daemon using cofig-pin to controll gpio pins
2017-05-15 daemon working with config-pin, all 16 channels
2017-05-23 new cape layout
    [16x.brd, 16x.sch]
2017-06-02 track Dcon binary
2017-06-05 change to match current code
2017-06-30 new cape design
    [16x.brd, 16x.sch, concape.sch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]
2017-07-07 insert working
2017-11-01 add flow chart for Pcon
2017-11-02 working on flow chart
2017-11-09 messing with pcb layout
2017-11-12 refactoring Pcon code to match flow chart
2017-11-12 clean up flow
2017-11-13 add Pcon flow chart to readme file
2017-11-19 delete/insert working
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2017-11-21 pin assignments changed to match old dauwire wrap cape
2017-11-29 starting to look at the sensor support
2017-11-30 cleaning up sensor support code
2017-12-08 track the Pcon binary
2017-12-09 fixed some schedule edit prompt issues
    [shared.h]
2017-12-10 redesign - not enough io pins
    [press-control.sch]
2017-12-18 code to display sensor vvalues working
2017-12-19 updating sensor code on the ESP8266s
2017-12-25 sort is still not working
    [shared.h]
2017-12-31 adding code to push sensor reading to dropbox
2017-12-31 Add sensor data push to push_ip
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2018-02-21 new board design
    [control panel.sch, main controler.sch, press-control.brd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]
2018-02-22 new control panel board
    [control panel.brd]
2018-02-25 messing with Eagle
    [control panel2.brd, control panel2.sch]
2018-04-12 add led control
    [control panel2.brd, control panel2.sch]
2018-04-18 add board for main controler
    [control master.sch]
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2018-08-03 change relay pin assignments
2018-08-03 messing with pin assignments
2018-11-13 mqtt implemented on esp8266 sensors
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

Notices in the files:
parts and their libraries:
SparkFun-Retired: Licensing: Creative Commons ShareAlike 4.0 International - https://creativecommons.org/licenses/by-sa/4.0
